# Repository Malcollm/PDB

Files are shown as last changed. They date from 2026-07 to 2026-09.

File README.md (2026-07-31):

# Humanoid Robot Power Distribution Board

This repository contains the power distribution board design for the Wiscohumanoids humanoid robot. The board distributes the main battery power to the robot’s high-current actuator system and generates regulated lower-voltage rails for compute, servos, sensors, and control electronics.

The PDB is designed around a 48 V main power system with onboard regulation for the robot’s auxiliary electronics.

## Project Overview

The power distribution board is responsible for taking the main battery input and safely distributing power throughout the robot. It includes high-current 48 V distribution, onboard buck converters, current sensing, precharge circuitry, and protection/disconnect circuitry.

The main goals of this board are:

- Distribute 48 V battery power to actuator rails
- Generate a 24 V compute rail
- Generate a 6 V servo rail for the robot hands
- Generate a 3.3 V rail for sensors and control electronics
- Monitor current on important power paths
- Limit inrush current during startup using precharge circuitry
- Separate actuator/servo power from compute/control power through protection and disconnect circuitry
- Protect the electrical system from voltage transients and fault conditions

## System Power Architecture

```text
Battery Input
    |
    |-- Precharge Circuit
    |
    |-- Main 48 V Power Rail
            |
            |-- Protection / Disconnect Circuitry
                    |
                    |-- Actuator / Servo Power Group
                    |       |
                    |       |-- 48 V Actuator Distribution
                    |       |
                    |       |-- 48 V to 6 V Buck Converter
                    |               |
                    |               |-- Hand Servos
                    |
                    |-- Compute / Control Power Group
                            |
                            |-- 48 V to 24 V Buck Converter
                            |       |
                            |       |-- Compute / Embedded Electronics
                            |
                            |-- 48 V to 3.3 V Buck Converter
                                    |
                                    |-- Sensors / Current Sensors / Control Logic
```

## Power Rails

| Rail | Purpose |
|---|---|
| 48 V | Main battery rail and actuator power distribution |
| 24 V | Compute and embedded electronics |
| 6 V | Servo motors in the robot hands |
| 3.3 V | Sensors, current sensors, and control logic |

## Major Board Features

### 48 V Actuator Distribution

The main power path distributes 48 V battery power to the robot’s actuator system. Because this rail carries the highest current on the board, the layout uses large copper pours, short current paths, and high-current connectors.

This section of the board is designed to minimize voltage drop and reduce heating under actuator load.

### Precharge Circuit

The board includes a precharge circuit to limit inrush current when the battery is connected. This is important because the board contains large bulk capacitance on the main 48 V rail.

During startup, the precharge path slowly charges the bulk capacitors before the main power path is fully enabled. This reduces stress on connectors, switches, relays, and other power components.

### Protection and Disconnect Circuitry

The PDB includes protection and disconnect circuitry that separates the main power system into two groups: the actuator/servo power group and the compute/control power group.

The actuator/servo group contains the 48 V actuator distribution and the 6 V hand servo rail. This group can be disconnected from the rest of the system so high-power motion components can be shut down independently.

The compute/control group contains the 12 V and 3.3 V rails. This allows the robot’s control electronics, sensors, and compute hardware to remain separated from the high-power actuator section.

This separation is important because it allows actuator power to be disabled while keeping control electronics available for monitoring, communication, and safe shutdown behavior.

Protection features include:

- Input transient voltage protection
- Precharge/inrush-current limiting
- Separation between actuator/servo power and compute/control power
- Reverse-current blocking where needed
- Current sensing for fault monitoring
- Support for external E-stop or main disconnect circuitry
- Bulk capacitance for load transients

### Current Sensing

Current sensors are included on important power paths so the robot can monitor how much current different parts of the system are drawing.

Current measurement is useful for:

- Detecting abnormal load conditions
- Debugging actuator behavior
- Estimating power usage
- Monitoring system health
- Adding future fault-detection logic

### Buck Converters

The PDB generates the lower-voltage rails from the main 48 V battery input using buck converters.

The onboard regulated rails are:

- 12 V for compute and embedded electronics
- 6 V for hand servos
- 3.3 V for sensors and control electronics

Each buck converter section includes the switching regulator circuit, input capacitance, output capacitance, feedback network, and supporting passives.

## Grounding

The board uses separate ground naming to keep high-current power paths and sensitive measurement/control paths organized.

Typical ground nets include:

| Net | Purpose |
|---|---|
| PGND | High-current power ground and switching converter return |
| AGND | Analog/sensor ground for feedback and current measurement circuits |

These grounds are not meant to be completely isolated systems. Instead, the separate names help control where large return currents flow and help keep sensor and feedback references cleaner.

## Design Status

This project is currently in development.

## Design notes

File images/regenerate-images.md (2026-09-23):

# Regenerating the images

Everything here is generated from the design files. A `pre-commit` hook rebuilds
it automatically and stages the results into that commit — enable it once per
clone with `git config core.hooksPath images/hooks`.

The hook only rebuilds what the commit actually affects:

| Staged change | Rebuilt |
| --- | --- |
| `Main_PDB.kicad_pcb` | `board-iso.png`, `board-top.png`, `layer-*.svg` |
| `*.kicad_sch` | `schematic.pdf` |

To rebuild by hand, run `./images/regenerate.sh` for everything, or narrow it
with `./images/regenerate.sh pcb` / `./images/regenerate.sh sch`. Set
`KICAD_CLI=...` if `kicad-cli` isn't at
`C:/Program Files/KiCad/10.0/bin/kicad-cli.exe`, or `SKIP_IMAGE_REGEN=1` before
a `git commit` to skip the hook once.

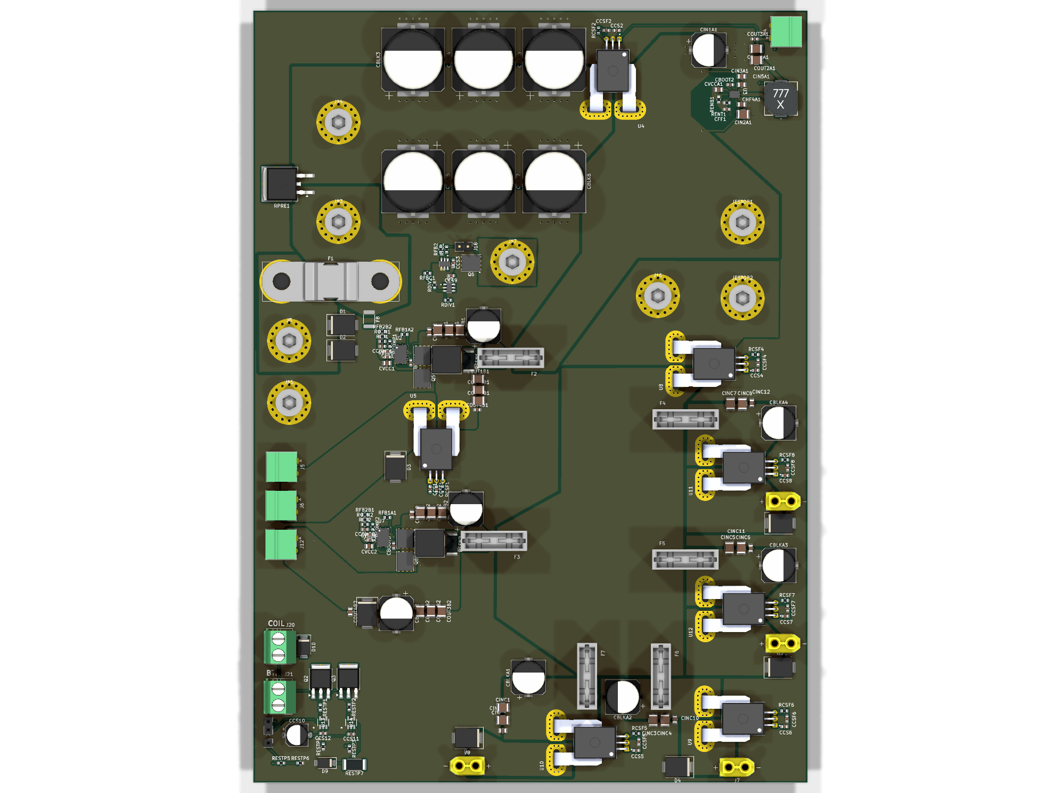
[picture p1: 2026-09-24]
images/board-top.png

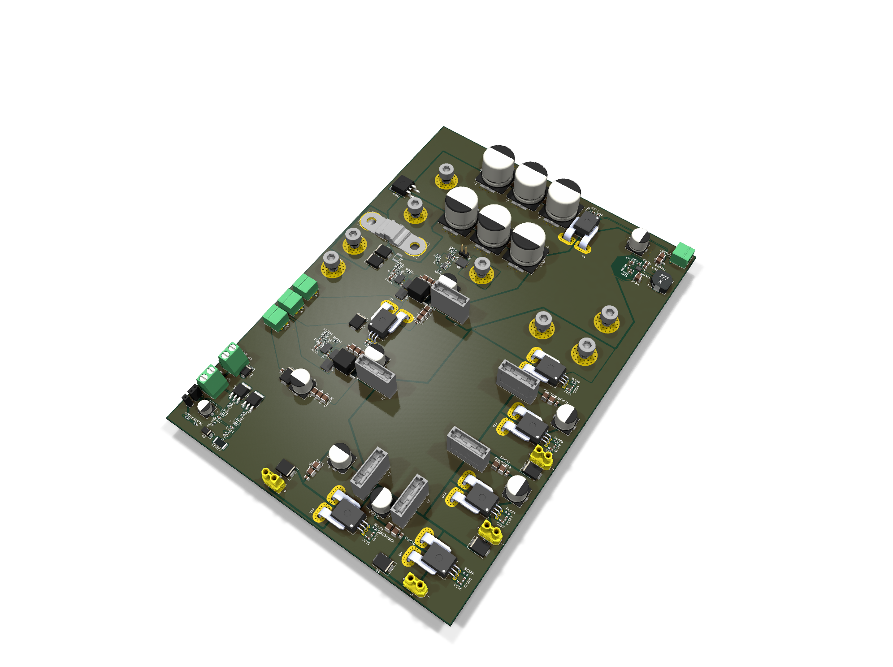
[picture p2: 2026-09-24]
images/board-iso.png

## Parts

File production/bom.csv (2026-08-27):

Designator | Footprint | Quantity | Value | LCSC Part #
CBLK3, CBLK4, CBLK5, CBLK6, CBLK7, CBLK8 | CP_Elec_18x17.5 | 6 | 470u
CBLKA1, CBLKA2, CBULK2, CIN1B2 | CP_Elec_10x10 | 4 | 100uF
CBLKA3, CBLKA4, CIN1A1, CIN1B1 | CP_Elec_10x10 | 4 | 47uF
CBOOT1, CBOOT3, CCS1, CCS2, CCS3, CCS4, CCS5, CCS6, CCS7, CCS8, CVDDA1, CVDDA2 | 0603 | 12 | 100n
CBOOT2, COUT3A1 | 0603 | 2 | 100nF
CBULK1 | CP_Elec_10x10 | 1 | 220uF
CCOMP1, CCOMP2 | 0603 | 2 | 6.8nF
CCSF1, CCSF2, CCSF4, CCSF5, CCSF6, CCSF7, CCSF8 | 0603 | 7 | 10n
CFF1 | 0603 | 1 | 20pF
CHF1, CHF2 | 0603 | 2 | 100pF
CHF4A1, CIN3A1 | 0805 | 2 | 220nF
CIN2A1 | 1210 | 1 | 4.7uF
CIN2B1, CIN2B2, CIN3B1, CIN3B2, CIN4B1, CIN4B2, CINC1, CINC2, CINC3, CINC4, CINC5, CINC6, CINC7, CINC8 | 1210 | 14 | 4.7u
CIN5A1, CIN5B1, CIN5B2, CINC10, CINC11, CINC12, CINC9, COUT4B1, COUT4B2 | 0805 | 9 | 100nF
COUT1A1, COUT2A1 | 1210 | 2 | 47uF
COUT1B1, COUT1B2, COUT2B1, COUT2B2, COUT3B1, COUT3B2 | 1210 | 6 | 22uF
CVCC1, CVCC2 | 0805 | 2 | 2.2u
CVCCA1 | 0805 | 1 | 1uF
D1, D10, D2, D3, D4, D5, D6, D7, D8 | D_SMC | 9 | TVS
F2, F3, F4, F5, F6, F7 | LITTELFUSE_178.6165.0002 | 6 | ~
J10, J7, J8, J9 | AMASS_XT30UPB-F_1x02_P5.0mm_Vertical | 4 | Conn_01x02_MountingPin
J5 | PhoenixContact_MC_1,5_2-G-3.81_1x02_P3.81mm_Horizontal | 1 | 24V Out -> Jetson
J6 | PhoenixContact_MC_1,5_2-G-3.81_1x02_P3.81mm_Horizontal | 1 | 24V Out -> USB-C-PD controller
JESTOP1 | MountingHole_5.3mm_M5_Pad | 1 | ESTOP_IN
JESTOP2 | MountingHole_5.3mm_M5_Pad | 1 | ESTOP_OUT
L1 | MSS1038183MLC | 1 | 18uH
L2 | L_Coilcraft_XAL8080-XXX | 1 | 10uH
L3 | L_Coilcraft_XAL8080-XXX | 1 | 4.7uH
Q4, Q5, Q6, Q7, Q8 | VSONP-8-1EP_5x6_P1.27mm | 5 | NMOS
RCOMP1, RCOMP2 | 0603 | 2 | 4.75k
RCON1, RCON2 | 0603 | 2 | 41.2k
RCSF1, RCSF2, RCSF4, RCSF5, RCSF6, RCSF7, RCSF8 | 0603 | 7 | 1k
RDIV1 | 0603 | 1 | 1M
RDIV2 | 0603 | 1 | 24.9k
RENB1 | 0603 | 1 | 43.2k
RENT1 | 0603 | 1 | 100k
RESTOP1, RESTOP2 | 0603 | 2 | 100
RESTOP3 | 0603 | 1 | 4.3k 1W
RESTOP4, RFB2B1, RFB2B2, RPD1, RPU1 | 0603 | 5 | 10k
RFB1, RFB2 | 0603 | 2 | 4.7R
RFB1A1 | 0603 | 1 | 64.9k
RFB1A2 | 0603 | 1 | 291k
RFBC1 | 0603 | 1 | 1.65M
RFBS1 | 0603 | 1 | 49.9k
RGND1 | 0603 | 1 | 0R
RPRE1 | 0603 | 1 | 80R
RSEN1, RSEN2 | 2512 | 2 | 0.002R
RSF1, RSF2 | 0603 | 2 | 47k
U1 | SOT95P280X145-6N | 1 | TLV3011AIDBVT
U10, U11, U12, U4, U5, U8, U9 | XDCR_ACS758LCB-100U-PFF-T | 7 | ACS758LCB-100U-PFF-T
U2 | QFN50P550X350X100-25N | 1 | LM5148RGYR
U3 | RNX0012B | 1 | LMR36015ARNXR
U6 | SOT95P280X145-6N | 1 | UCC27511DBVR

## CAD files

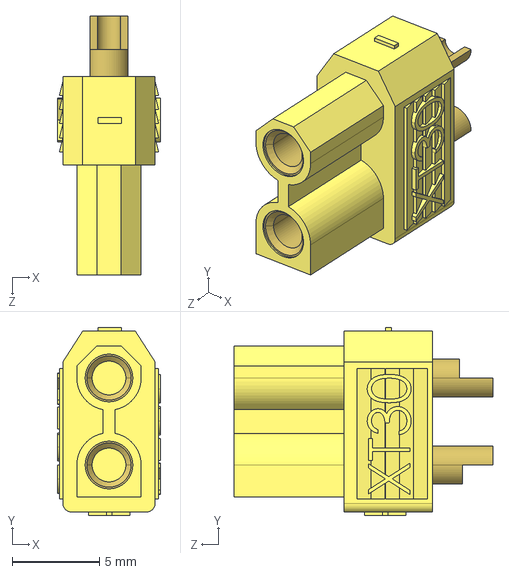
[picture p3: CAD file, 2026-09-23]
3d Models/XT30-F_m.ver.STEP
5.90 x 10.8 x 14.9 mm

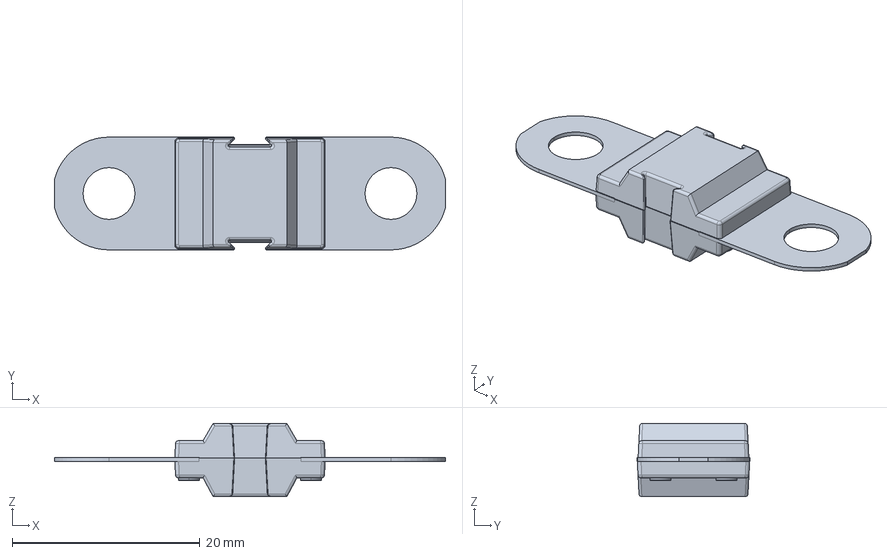
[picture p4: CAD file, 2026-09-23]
3d Models/3D_model_BF1_142.5631.0000_BF1_58v_M5_0.4mm (1).stp
41.6 x 12.0 x 7.80 mm

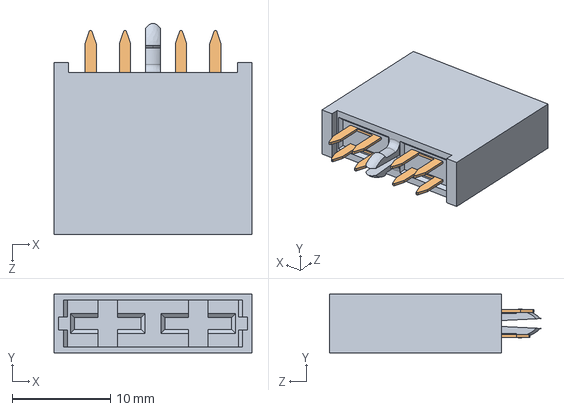
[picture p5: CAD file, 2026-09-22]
3d Models/178.6165.0000 - Holder FLR (ATO) Step model.step
20.1 x 6.00 x 21.5 mm

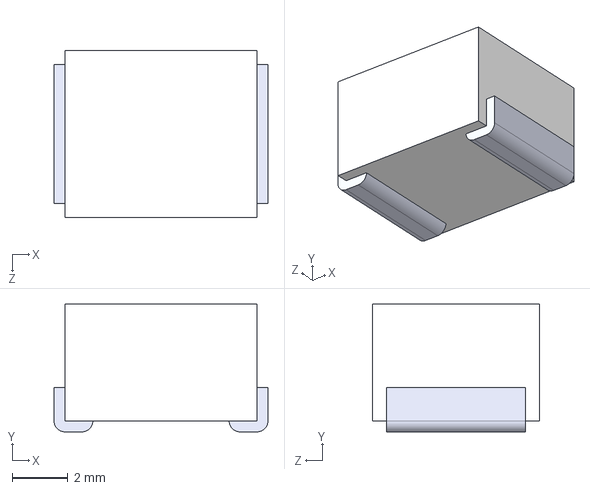
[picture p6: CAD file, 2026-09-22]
3d Models/2822HC100-RTR--3DModel-STEP-510211.STEP
7.70 x 4.60 x 6.00 mm

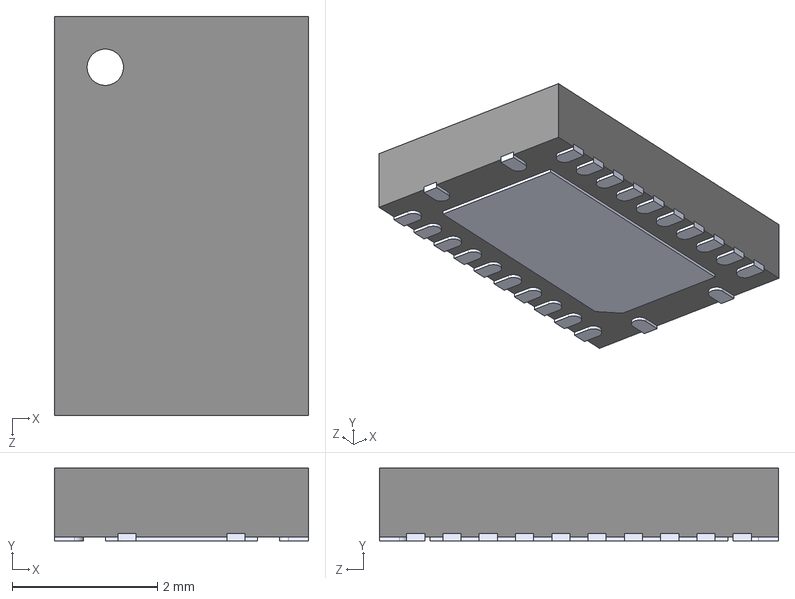
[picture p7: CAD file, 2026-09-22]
3d Models/LM5148RGYR--3DModel-STEP-56544.STEP
3.50 x 1.00 x 5.50 mm

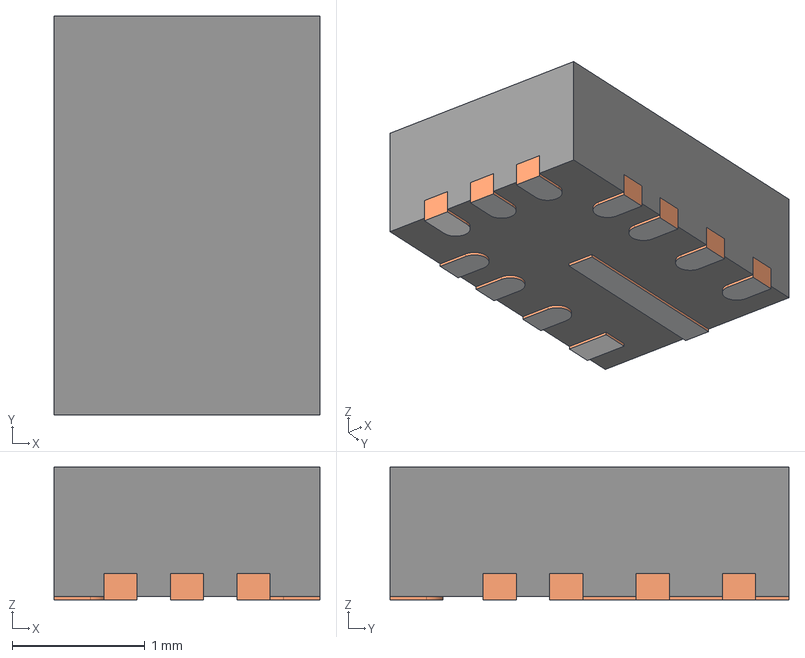
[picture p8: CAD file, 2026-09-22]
3d Models/TI_LMR3601ARNXR.stp
2.00 x 3.00 x 1.00 mm
FRAME-RNX0012A
BODY-QFN
PIN1-ID

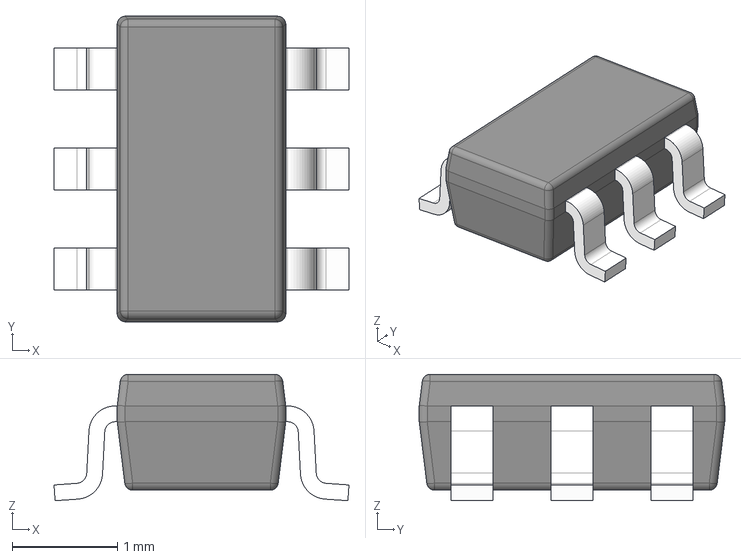
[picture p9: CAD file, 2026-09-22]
3d Models/DBV0006A.stp
2.80 x 2.90 x 1.20 mm
BODY-SOT
LEAD-SOT x 6

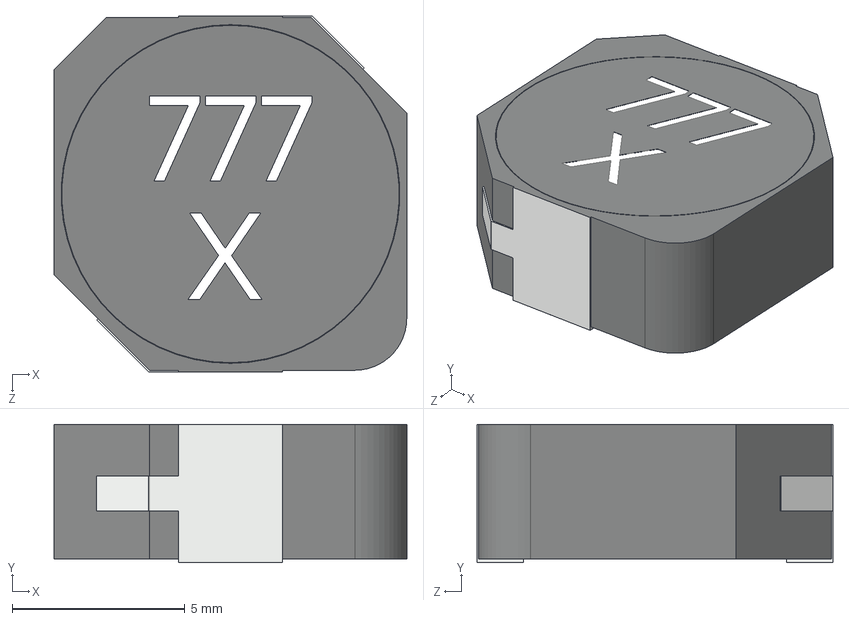
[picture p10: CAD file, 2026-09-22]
3d Models/MSS1038T.STEP
10.2 x 4.00 x 10.3 mm

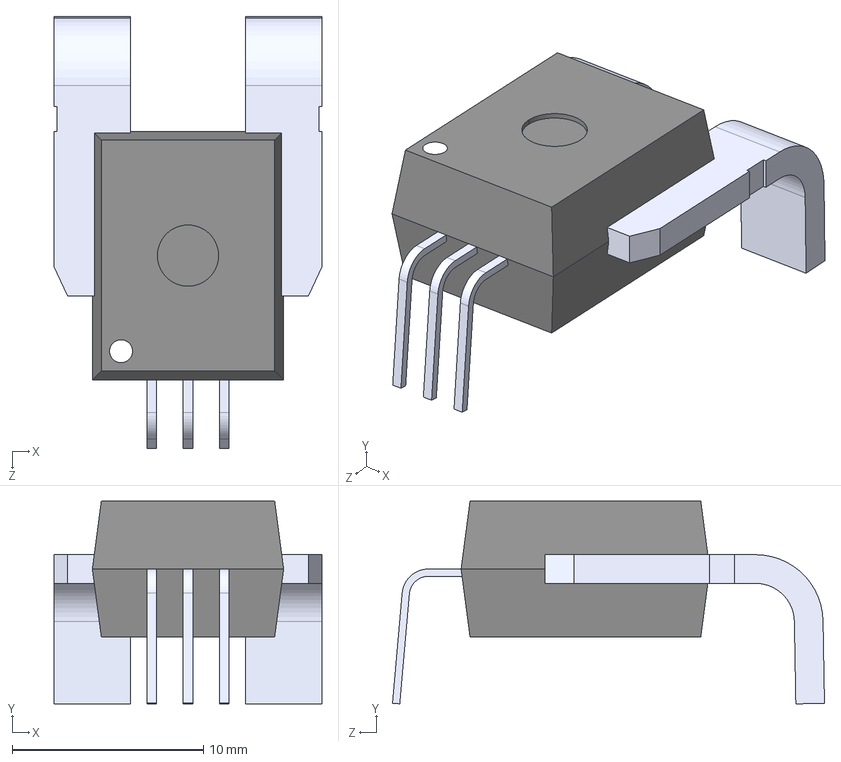
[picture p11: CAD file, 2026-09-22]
3d Models/ACS758LCB-100U-PFF-T.STEP
14.0 x 10.6 x 22.6 mm

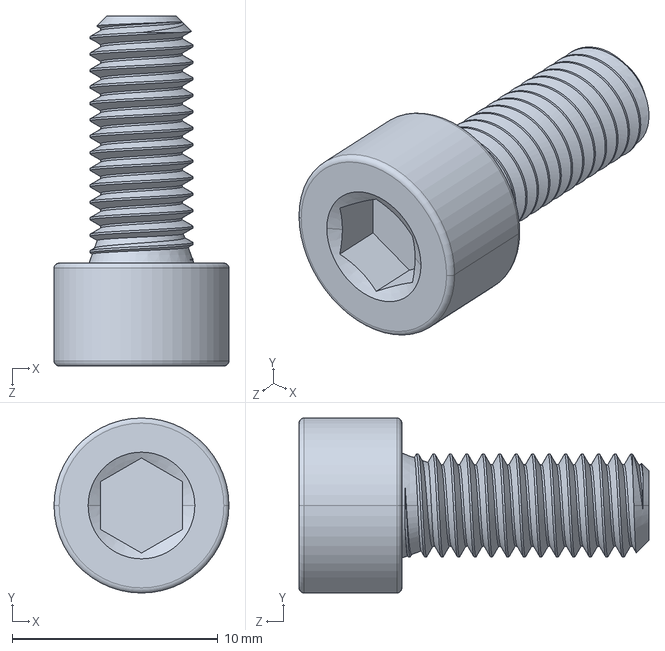
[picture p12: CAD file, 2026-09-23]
3d Models/91292A125_18-8 Stainless Steel Socket Head Screw.STEP
8.50 x 8.50 x 17.0 mm

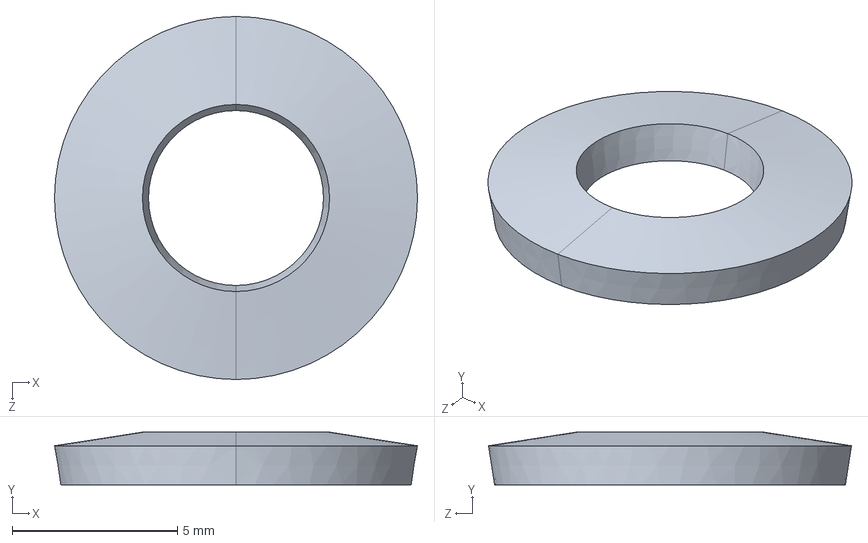
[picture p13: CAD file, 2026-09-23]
3d Models/91477A123_18-8 Stainless Steel Spring Lock Washer.STEP
11.0 x 1.60 x 11.0 mm

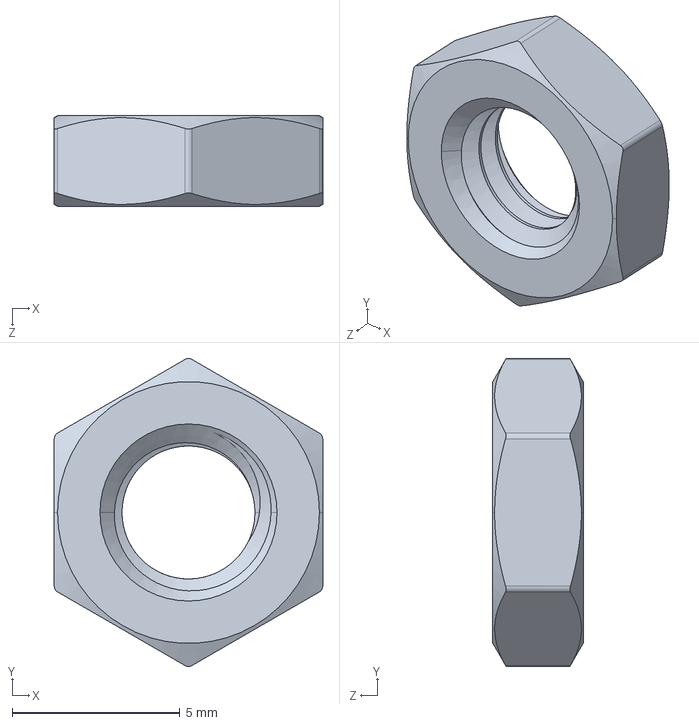
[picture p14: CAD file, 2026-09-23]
3d Models/90710A037_18-8 Stainless Steel Thin-Profile Hex Nut.STEP
8.00 x 9.18 x 2.70 mm

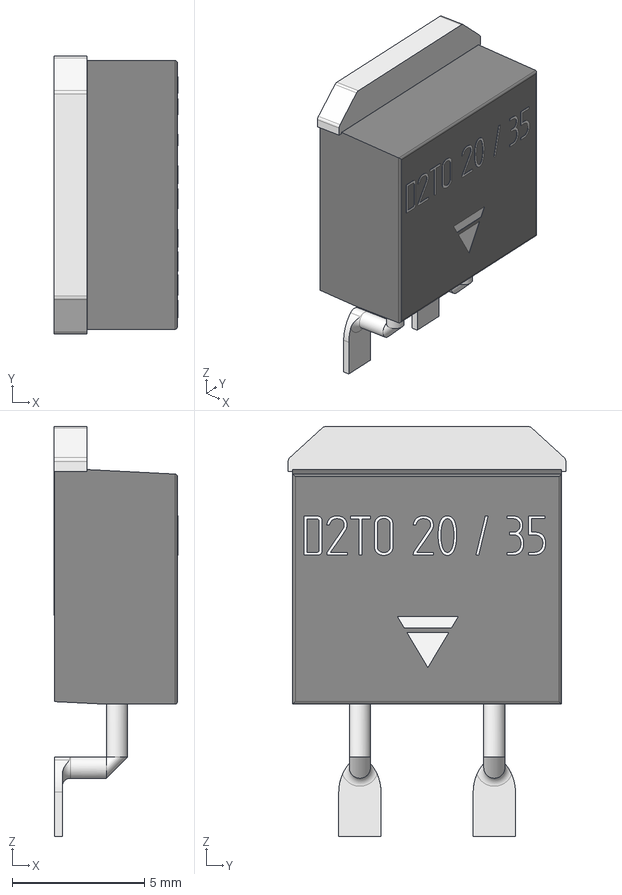
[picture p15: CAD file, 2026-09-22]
3d Models/52338943_D2TO.stp
4.69 x 10.5 x 15.5 mm
dissipateur
sortie-oa0
sortie-oa1
moulage D2TO 20_35

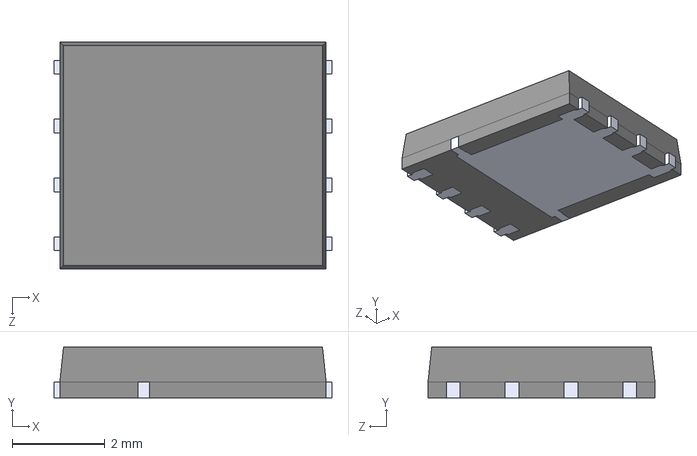
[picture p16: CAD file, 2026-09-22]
3d Models/CSD18533Q5A.STEP
6.00 x 1.10 x 4.90 mm

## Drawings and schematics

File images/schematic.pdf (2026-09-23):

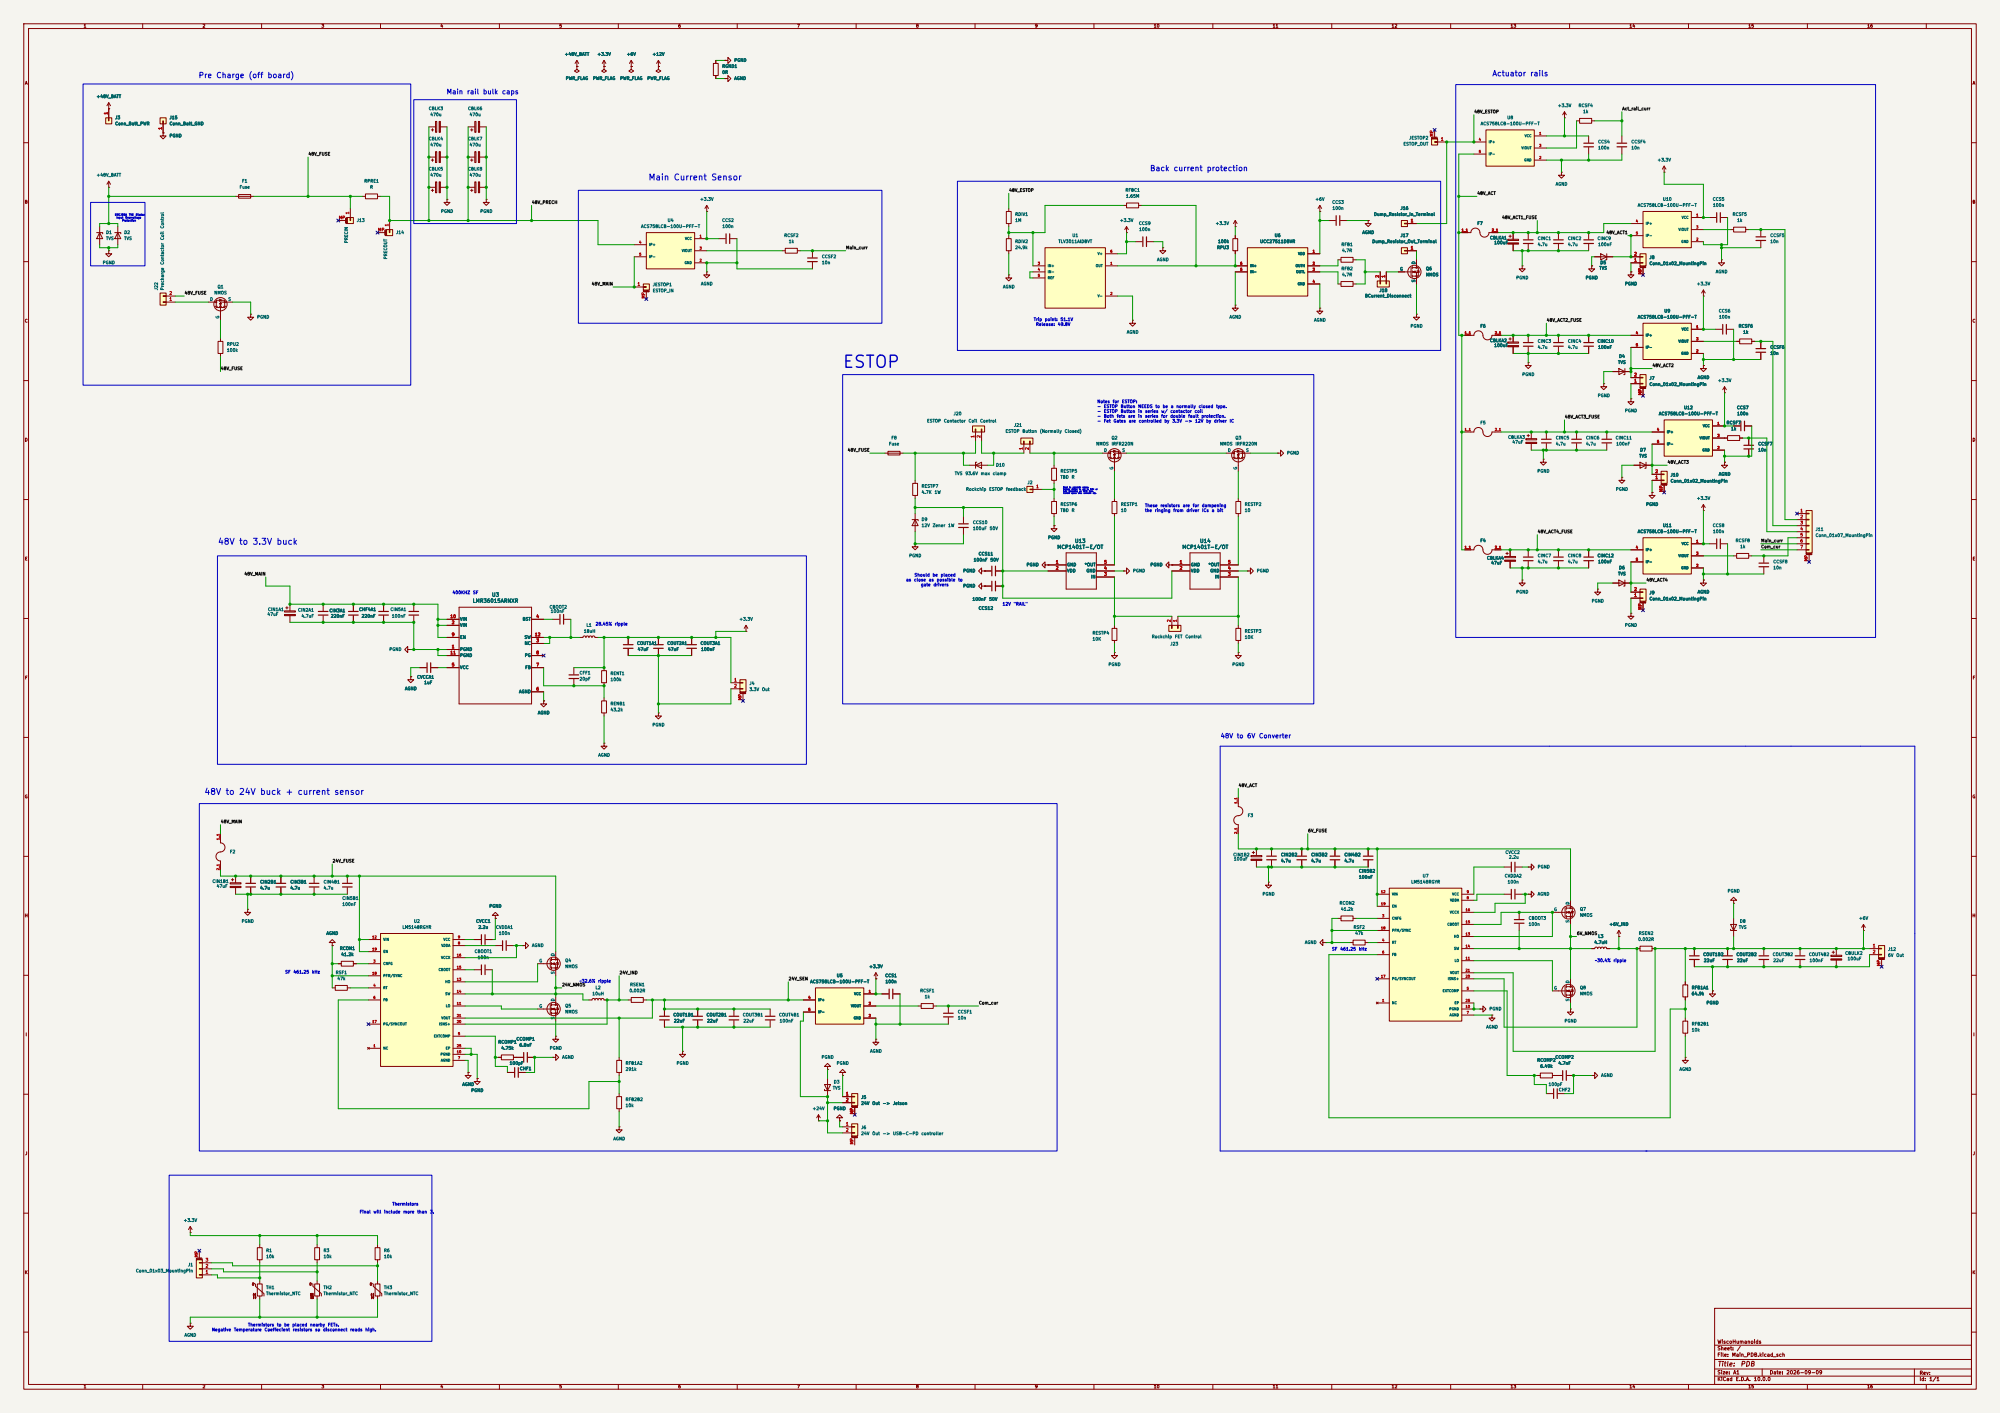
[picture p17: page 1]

Pre Charge (off board)

Trip point: 51.1V Release: 49.8V Main rail bulk caps

ESTOP
ESTOP Contactor Coil Control CCS12

Notes for ESTOP: - ESTOP Button NEEDS to be a normally closed type. - ESTOP Button in series w/ contactor coil - Both fets are in series for double fault protection. - Fet Gates are controlled by 3.3V -> 12V by driver IC

ESTOP Button (Normally Closed) GND

Need to calculate values. Voltage divider to get to 3.3v or 1.8v depending on GPIO type. Current specs also unknown atp. 12V "RAIL" 28.45% ripple

These resistors are for dampening

the ringing from driver ICs a bit 48V to 24V buck + current sensor

Should be placed
as close as possible to

24V Out -> USB-C-PD controller

Final will include more than 3.

Thermistors to be placed nearby FETs. Negative Temperature Coeffecient resistors so disconnect reads high.

Size: A1 | Rev:

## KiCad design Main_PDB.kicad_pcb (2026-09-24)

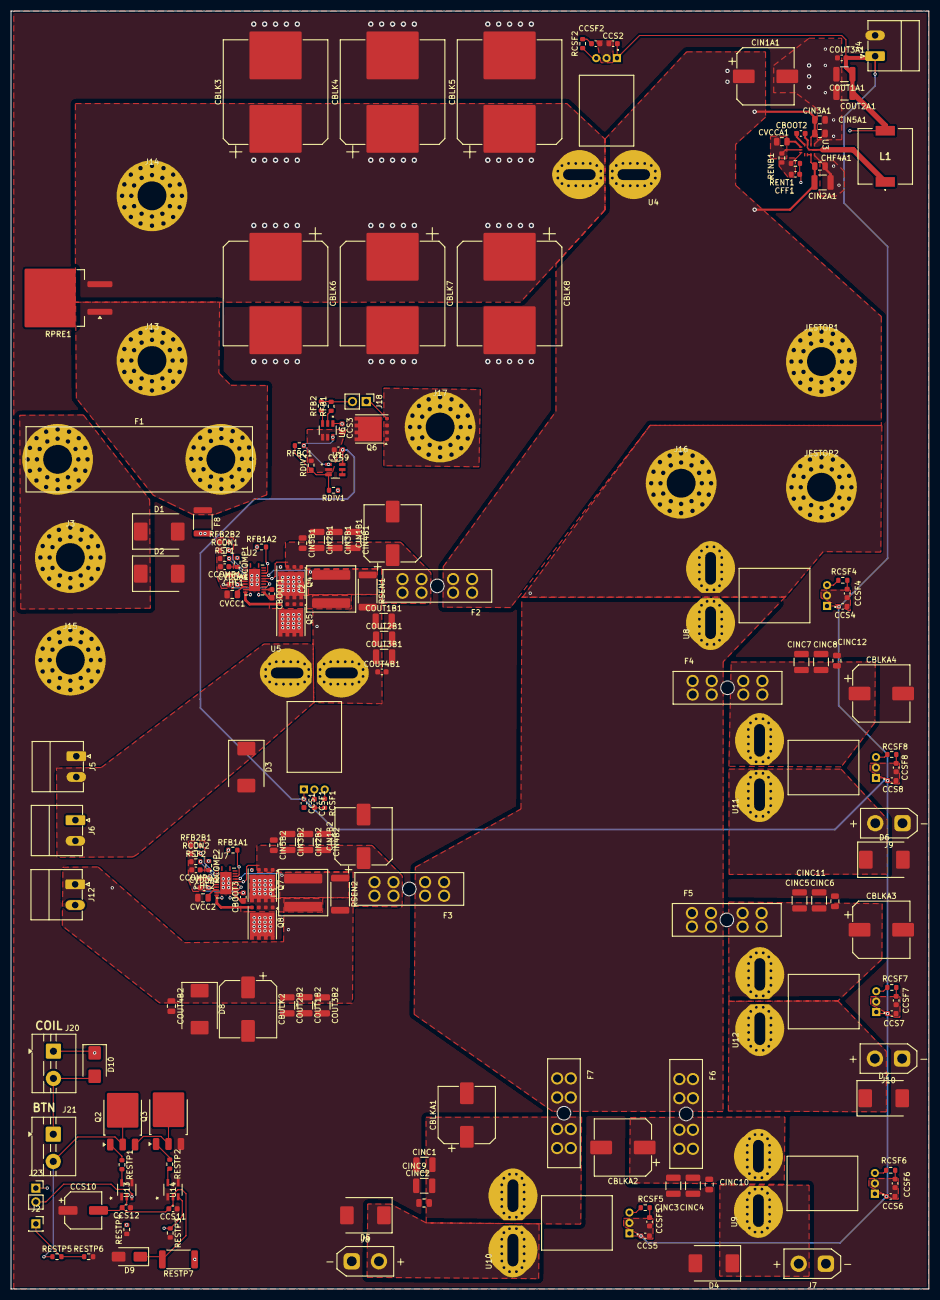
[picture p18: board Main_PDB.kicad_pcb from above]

Board: 6 copper layers, 168.6 x 234.8 mm, 178 parts (0 on the bottom side), 83 nets.

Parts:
CBLK3, CBLK4, CBLK5, CBLK6, CBLK7, CBLK8: 470u; CP_Elec_18x17.5
CBLKA1, CBLKA2: 100uF; CP_Elec_10x10
CBLKA3, CBLKA4: 47uF; CP_Elec_10x10
CBOOT1, CBOOT3: 100n; C_0603_1608Metric
CBOOT2: 100nF; C_0603_1608Metric
CBULK2: 100uF; CP_Elec_10x10
CCOMP1: 6.8nF; C_0603_1608Metric
CCOMP2: 4.7nF; C_0603_1608Metric
CCS1, CCS2, CCS3, CCS4, CCS5, CCS6, CCS7, CCS8, CCS9: 100n; C_0603_1608Metric
CCS10: 100uF 50V; CP_Elec_6.3x5.4
CCS11, CCS12: 100nF 50V; C_0603_1608Metric
CCSF1, CCSF2, CCSF4, CCSF5, CCSF6, CCSF7, CCSF8: 10n; C_0603_1608Metric
CFF1: 20pF; C_0603_1608Metric
CHF1, CHF2: 100pF; C_0603_1608Metric
CHF4A1: 220nF; C_0805_2012Metric
CIN1A1, CIN1B1: 47uF; CP_Elec_10x10
CIN1B2: 100uF; CP_Elec_10x10
CIN2A1: 4.7uF; C_1210_3225Metric
CIN2B1, CIN2B2, CIN3B1, CIN3B2, CIN4B1, CIN4B2: 4.7u; C_1210_3225Metric
CIN3A1: 220nF; C_0805_2012Metric
CIN5A1, CIN5B1, CIN5B2: 100nF; C_0805_2012Metric
CINC1, CINC2, CINC3, CINC4, CINC5, CINC6, CINC7, CINC8: 4.7u; C_1210_3225Metric
CINC9, CINC10, CINC11, CINC12: 100nF; C_0805_2012Metric
COUT1A1, COUT2A1: 47uF; C_1210_3225Metric
COUT1B1, COUT1B2, COUT2B1, COUT2B2, COUT3B1, COUT3B2: 22uF; C_1210_3225Metric
COUT3A1, COUT4B1: 100nF; C_0603_1608Metric
COUT4B2: 100nF; C_0805_2012Metric
CVCC1, CVCC2: 2.2u; C_0805_2012Metric
CVCCA1: 1uF; C_0805_2012Metric
CVDDA1, CVDDA2: 100n; C_0603_1608Metric
D1, D2, D3, D4, D5, D6, D7, D8: TVS; D_SMC
D9: 12V Zener 1W; D_SMA
D10: TVS 93.6V max clamp; D_SMB
F1: Fuse; FUSE_BF1_M5_100A
F2, F3, F4, F5, F6, F7: LITTELFUSE_178.6165.0002
F8: Fuse; Fuse_1812_4532Metric
J2: Rockchip ESTOP feedback; PinSocket_1x01_P2.54mm_Vertical
J3: Conn_Batt_PWR; MountingHole_5.3mm_M5_Pad_Via_HP
J4: 3.3V Out; PhoenixContact_MC_1,5_2-G-3.81_1x02_P3.81mm_Horizontal
J5: 24V Out -> Jetson; PhoenixContact_MC_1,5_2-G-3.81_1x02_P3.81mm_Horizontal
J6: 24V Out -> USB-C-PD controller; PhoenixContact_MC_1,5_2-G-3.81_1x02_P3.81mm_Horizontal
J7, J8, J9, J10: Conn_01x02_MountingPin; AMASS_XT30UPB-F_1x02_P5.0mm_Vertical
J12: 6V Out; PhoenixContact_MC_1,5_2-G-3.81_1x02_P3.81mm_Horizontal
J13: PRECIN; MountingHole_5.3mm_M5_Pad_Via_HP
J14: PRECOUT; MountingHole_5.3mm_M5_Pad_Via_HP
J15: Conn_Batt_GND; MountingHole_5.3mm_M5_Pad_Via_HP
J16: Dump_Resistor_In_Terminal; MountingHole_5.3mm_M5_Pad_Via_HP
J17: Dump_Resistor_Out_Terminal; MountingHole_5.3mm_M5_Pad_Via_HP
J18: BCurrent_Disconnect; PinHeader_1x02_P2.54mm_Vertical
J20: ESTOP Contactor Coil Control; TerminalBlock_MaiXu_MX126-5.0-02P_1x02_P5.00mm
J21: ESTOP Button (Normally Closed); TerminalBlock_MaiXu_MX126-5.0-02P_1x02_P5.00mm
J23: Rockchip FET Control; PinSocket_1x02_P2.54mm_Vertical
JESTOP1: ESTOP_IN; MountingHole_5.3mm_M5_Pad_Via_HP
JESTOP2: ESTOP_OUT; MountingHole_5.3mm_M5_Pad_Via_HP
L1: 18uH; MSS1038183MLC
L2: 10uH; L_Coilcraft_XAL8080-XXX
L3: 4.7uH; L_Coilcraft_XAL8080-XXX
Q2, Q3: NMOS IRFR220N; TO-252-3_TabPin2
Q4, Q5, Q6, Q7, Q8: NMOS; VSONP-8-1EP_5x6_P1.27mm
RCOMP1: 4.75k; R_0603_1608Metric
RCOMP2: 6.49k; R_0603_1608Metric
RCON1, RCON2: 41.2k; R_0603_1608Metric
RCSF1, RCSF2, RCSF4, RCSF5, RCSF6, RCSF7, RCSF8: 1k; R_0603_1608Metric
RDIV1: 1M; R_0603_1608Metric
RDIV2: 24.9k; R_0603_1608Metric
RENB1: 43.2k; R_0603_1608Metric
RENT1: 100k; R_0603_1608Metric
RESTP1, RESTP2: 10; R_0603_1608Metric
RESTP3, RESTP4: 10K; R_0603_1608Metric
RESTP5, RESTP6: TBD R; R_0603_1608Metric
RESTP7: 4.7K 1W; R_2512_6332Metric
RFB1, RFB2: 4.7R; R_0603_1608Metric
RFB1A1: 64.9k; R_0603_1608Metric
RFB1A2: 291k; R_0603_1608Metric
RFB2B1, RFB2B2: 10k; R_0603_1608Metric
RFBC1: 1.65M; R_0603_1608Metric
RPRE1: R; TO-263-2_Resistor
RSEN1, RSEN2: 0.002R; R_2512_6332Metric
RSF1, RSF2: 47k; R_0603_1608Metric
U1: TLV3011AIDBVT; SOT95P280X145-6N
U2, U7: LM5148RGYR; QFN50P550X350X100-25N
U3: LMR36015ARNXR; RNX0012B
U4, U5, U8, U9, U10, U11, U12: ACS758LCB-100U-PFF-T; XDCR_ACS758LCB-100U-PFF-T
U6: UCC27511DBVR; SOT95P280X145-6N
U13, U14: MCP1401T-E/OT; SOT-23-5_MC_MCH

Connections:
+3.3V: CCS1.1, CCS2.2, CCS4.2, CCS5.1, CCS6.1, CCS7.1, CCS8.1, CCS9.1, CFF1.1, COUT1A1.1, COUT2A1.1, COUT3A1.1, J4.1, L1.2, RENT1.1, U1.6 (V+), U4.1 (VCC), U5.1 (VCC), U8.1 (VCC), U9.1 (VCC), U10.1 (VCC), U11.1 (VCC), U12.1 (VCC)
+6V: CBULK2.1, CCS3.1, COUT1B2.1, COUT2B2.1, COUT3B2.1, COUT4B2.1, D8.1 (K), J12.1, RFB1A1.2, RSEN2.2, U6.1 (VDD), U7.21 (VOUT)
+6V_IND: L3.2, RSEN2.1, U7.20 (ISNS+)
+24V: D3.1 (K), J5.2, J6.2, U5.5 (IP-), U5.5_1 (IP-), U5.5_2 (IP-), U5.5_3 (IP-), U5.5_4 (IP-), U5.5_5 (IP-), U5.5_6 (IP-), U5.5_7 (IP-), U5.5_8 (IP-), U5.5_9 (IP-), U5.5_10 (IP-), U5.5_11 (IP-), U5.5_12 (IP-), U5.5_13 (IP-), U5.5_14 (IP-), U5.5_15 (IP-), U5.5_16 (IP-)
+48V_BATT: D1.1 (K), D2.1 (K), F1.1, J3.1 (Pin_1_1)
/6V_FUSE: CIN1B2.1, CIN2B2.2, CIN3B2.2, CIN4B2.2, CIN5B2.2, F3.2_1, F3.2_2, F3.2_3, F3.2_4, Q7.1 (D), U7.12 (VIN), U7.19 (EN)
/6V_NMOS: CBOOT3.1, L3.1, Q7.3 (S), Q8.1 (D), U7.14 (SW)
/24V_FUSE: CIN1B1.1, CIN2B1.2, CIN3B1.2, CIN4B1.2, CIN5B1.2, F2.2_1, F2.2_2, F2.2_3, F2.2_4, Q4.1 (D), U2.12 (VIN), U2.19 (EN)
/24V_IND: L2.2, RSEN1.1, U2.20 (ISNS+)
/24V_NMOS: CBOOT1.2, L2.1, Q4.3 (S), Q5.1 (D), U2.14 (SW)
/24V_SEN: COUT1B1.1, COUT2B1.1, COUT3B1.1, COUT4B1.1, RFB1A2.2, RSEN1.2, U2.21 (VOUT), U5.4 (IP+), U5.4_1 (IP+), U5.4_2 (IP+), U5.4_3 (IP+), U5.4_4 (IP+), U5.4_5 (IP+), U5.4_6 (IP+), U5.4_7 (IP+), U5.4_8 (IP+), U5.4_9 (IP+), U5.4_10 (IP+), U5.4_11 (IP+), U5.4_12 (IP+), U5.4_13 (IP+), U5.4_14 (IP+), U5.4_15 (IP+), U5.4_16 (IP+)
/48V_ACT: F3.1_1, F3.1_2, F3.1_3, F3.1_4, F4.1_1, F4.1_2, F4.1_3, F4.1_4, F5.1_1, F5.1_2, F5.1_3, F5.1_4, F6.1_1, F6.1_2, F6.1_3, F6.1_4, F7.1_1, F7.1_2, F7.1_3, F7.1_4, U8.5 (IP-), U8.5_1 (IP-), U8.5_2 (IP-), U8.5_3 (IP-), U8.5_4 (IP-), U8.5_5 (IP-), U8.5_6 (IP-), U8.5_7 (IP-), U8.5_8 (IP-), U8.5_9 (IP-), U8.5_10 (IP-), U8.5_11 (IP-), U8.5_12 (IP-), U8.5_13 (IP-), U8.5_14 (IP-), U8.5_15 (IP-), U8.5_16 (IP-)
/48V_ACT1: D5.1 (K), J8.2, U10.5 (IP-), U10.5_1 (IP-), U10.5_2 (IP-), U10.5_3 (IP-), U10.5_4 (IP-), U10.5_5 (IP-), U10.5_6 (IP-), U10.5_7 (IP-), U10.5_8 (IP-), U10.5_9 (IP-), U10.5_10 (IP-), U10.5_11 (IP-), U10.5_12 (IP-), U10.5_13 (IP-), U10.5_14 (IP-), U10.5_15 (IP-), U10.5_16 (IP-)
/48V_ACT1_FUSE: CBLKA1.1, CINC1.2, CINC2.2, CINC9.1, F7.2_1, F7.2_2, F7.2_3, F7.2_4, U10.4 (IP+), U10.4_1 (IP+), U10.4_2 (IP+), U10.4_3 (IP+), U10.4_4 (IP+), U10.4_5 (IP+), U10.4_6 (IP+), U10.4_7 (IP+), U10.4_8 (IP+), U10.4_9 (IP+), U10.4_10 (IP+), U10.4_11 (IP+), U10.4_12 (IP+), U10.4_13 (IP+), U10.4_14 (IP+), U10.4_15 (IP+), U10.4_16 (IP+)
/48V_ACT2: D4.1 (K), J7.2, U9.5 (IP-), U9.5_1 (IP-), U9.5_2 (IP-), U9.5_3 (IP-), U9.5_4 (IP-), U9.5_5 (IP-), U9.5_6 (IP-), U9.5_7 (IP-), U9.5_8 (IP-), U9.5_9 (IP-), U9.5_10 (IP-), U9.5_11 (IP-), U9.5_12 (IP-), U9.5_13 (IP-), U9.5_14 (IP-), U9.5_15 (IP-), U9.5_16 (IP-)
/48V_ACT2_FUSE: CBLKA2.1, CINC3.2, CINC4.2, CINC10.1, F6.2_1, F6.2_2, F6.2_3, F6.2_4, U9.4 (IP+), U9.4_1 (IP+), U9.4_2 (IP+), U9.4_3 (IP+), U9.4_4 (IP+), U9.4_5 (IP+), U9.4_6 (IP+), U9.4_7 (IP+), U9.4_8 (IP+), U9.4_9 (IP+), U9.4_10 (IP+), U9.4_11 (IP+), U9.4_12 (IP+), U9.4_13 (IP+), U9.4_14 (IP+), U9.4_15 (IP+), U9.4_16 (IP+)
/48V_ACT3: D7.1 (K), J10.2, U12.5 (IP-), U12.5_1 (IP-), U12.5_2 (IP-), U12.5_3 (IP-), U12.5_4 (IP-), U12.5_5 (IP-), U12.5_6 (IP-), U12.5_7 (IP-), U12.5_8 (IP-), U12.5_9 (IP-), U12.5_10 (IP-), U12.5_11 (IP-), U12.5_12 (IP-), U12.5_13 (IP-), U12.5_14 (IP-), U12.5_15 (IP-), U12.5_16 (IP-)
/48V_ACT3_FUSE: CBLKA3.1, CINC5.2, CINC6.2, CINC11.1, F5.2_1, F5.2_2, F5.2_3, F5.2_4, U12.4 (IP+), U12.4_1 (IP+), U12.4_2 (IP+), U12.4_3 (IP+), U12.4_4 (IP+), U12.4_5 (IP+), U12.4_6 (IP+), U12.4_7 (IP+), U12.4_8 (IP+), U12.4_9 (IP+), U12.4_10 (IP+), U12.4_11 (IP+), U12.4_12 (IP+), U12.4_13 (IP+), U12.4_14 (IP+), U12.4_15 (IP+), U12.4_16 (IP+)
/48V_ACT4: D6.1 (K), J9.2, U11.5 (IP-), U11.5_1 (IP-), U11.5_2 (IP-), U11.5_3 (IP-), U11.5_4 (IP-), U11.5_5 (IP-), U11.5_6 (IP-), U11.5_7 (IP-), U11.5_8 (IP-), U11.5_9 (IP-), U11.5_10 (IP-), U11.5_11 (IP-), U11.5_12 (IP-), U11.5_13 (IP-), U11.5_14 (IP-), U11.5_15 (IP-), U11.5_16 (IP-)
/48V_ACT4_FUSE: CBLKA4.1, CINC7.2, CINC8.2, CINC12.1, F4.2_1, F4.2_2, F4.2_3, F4.2_4, U11.4 (IP+), U11.4_1 (IP+), U11.4_2 (IP+), U11.4_3 (IP+), U11.4_4 (IP+), U11.4_5 (IP+), U11.4_6 (IP+), U11.4_7 (IP+), U11.4_8 (IP+), U11.4_9 (IP+), U11.4_10 (IP+), U11.4_11 (IP+), U11.4_12 (IP+), U11.4_13 (IP+), U11.4_14 (IP+), U11.4_15 (IP+), U11.4_16 (IP+)
/48V_ESTOP: J16.1 (Pin_1_1), JESTOP2.1 (Pin_1_1), RDIV1.1, U8.4 (IP+), U8.4_1 (IP+), U8.4_2 (IP+), U8.4_3 (IP+), U8.4_4 (IP+), U8.4_5 (IP+), U8.4_6 (IP+), U8.4_7 (IP+), U8.4_8 (IP+), U8.4_9 (IP+), U8.4_10 (IP+), U8.4_11 (IP+), U8.4_12 (IP+), U8.4_13 (IP+), U8.4_14 (IP+), U8.4_15 (IP+), U8.4_16 (IP+)
/48V_FUSE: F1.2, F8.1, J13.1 (Pin_1_1), RPRE1.1
/48V_MAIN: CHF4A1.1, CIN1A1.1, CIN2A1.1, CIN3A1.1, CIN5A1.1, F2.1_1, F2.1_2, F2.1_3, F2.1_4, JESTOP1.1 (Pin_1_1), U3.2 (VIN), U3.9 (EN), U3.10 (VIN), U4.5 (IP-), U4.5_1 (IP-), U4.5_2 (IP-), U4.5_3 (IP-), U4.5_4 (IP-), U4.5_5 (IP-), U4.5_6 (IP-), U4.5_7 (IP-), U4.5_8 (IP-), U4.5_9 (IP-), U4.5_10 (IP-), U4.5_11 (IP-), U4.5_12 (IP-), U4.5_13 (IP-), U4.5_14 (IP-), U4.5_15 (IP-), U4.5_16 (IP-)
/48V_PRECH: CBLK3.1, CBLK4.1, CBLK5.1, CBLK6.1, CBLK7.1, CBLK8.1, J14.1 (Pin_1_1), RPRE1.2, U4.4 (IP+), U4.4_1 (IP+), U4.4_2 (IP+), U4.4_3 (IP+), U4.4_4 (IP+), U4.4_5 (IP+), U4.4_6 (IP+), U4.4_7 (IP+), U4.4_8 (IP+), U4.4_9 (IP+), U4.4_10 (IP+), U4.4_11 (IP+), U4.4_12 (IP+), U4.4_13 (IP+), U4.4_14 (IP+), U4.4_15 (IP+), U4.4_16 (IP+)
/Act_rail_curr: CCSF4.2, RCSF4.2
/Com_cur: CCSF1.2, RCSF1.2
/Main_curr: CCSF2.2, RCSF2.2
AGND: CCOMP1.2, CCOMP2.2, CCS1.2, CCS2.1, CCS3.2, CCS4.1, CCS5.2, CCS6.2, CCS7.2, CCS8.2, CCS9.2, CCSF1.1, CCSF2.1, CCSF4.1, CCSF5.1, CCSF6.1, CCSF7.1, CCSF8.1, CHF1.2, CHF2.2, CVCCA1.1, CVDDA1.1, CVDDA2.1, RCON1.1, RCON2.1, RDIV2.2, RENB1.2, RFB2B1.1, RFB2B2.1, RSF1.1, RSF2.1, U1.2 (V-), U2.7 (AGND), U2.16 (VCCX), U2.18 (PFM/SYNC), U3.6 (AGND), U4.2 (GND), U5.2 (GND), U6.4 (GND), U6.5 (IN-), U7.7 (AGND), U7.16 (VCCX), U7.18 (PFM/SYNC), U8.2 (GND), U9.2 (GND), U10.2 (GND), U11.2 (GND), U12.2 (GND)
unnamed: CCOMP1.1, RCOMP1.2
unnamed: CCOMP2.1, RCOMP2.2
unnamed: CCS10.2, CCS11.2, CCS12.2, D9.1 (K), RESTP7.2, U13.2 (VDD), U14.2 (VDD)
unnamed: D10.2 (A), J20.2, J21.1
unnamed: D10.1 (K), F8.2, J20.1, RESTP7.1
unnamed: J2.1 (Pin_1_1), RESTP5.2, RESTP6.1
unnamed: CCSF5.2, RCSF5.2
unnamed: CCSF6.2, RCSF6.2
unnamed: CCSF7.2, RCSF7.2
unnamed: CCSF8.2, RCSF8.2
unnamed: J17.1 (Pin_1_1), Q6.1 (D)
unnamed: J18.1, Q6.2 (G)
unnamed: J18.2, RFB1.2, RFB2.2
unnamed: J21.2, Q2.2 (D), RESTP5.1
unnamed: J23.1, RESTP3.1, U14.3 (IN)
unnamed: J23.2, RESTP4.2, U13.3 (IN)
unnamed: Q2.1 (G), RESTP1.1
unnamed: Q2.3 (S), Q3.2 (D)
unnamed: Q3.1 (G), RESTP2.1
unnamed: Q4.2 (G), U2.13 (HO)
unnamed: Q5.2 (G), U2.11 (LO)
unnamed: CBOOT3.2, Q7.2 (G), U7.13 (HO), U7.15 (CBOOT)
unnamed: Q8.2 (G), U7.11 (LO)
unnamed: RDIV1.2, RDIV2.1, RFBC1.2, U1.3 (IN+)
unnamed: U1.4 (IN-), U1.5 (REF)
unnamed: RFBC1.1, U1.1 (OUT), U6.6 (IN+)
unnamed: CBOOT1.1, U2.15 (CBOOT)
unnamed: RCON1.2, U2.3 (CNFG)
unnamed: CHF1.1, RCOMP1.1, U2.5 (EXTCOMP)
unnamed: RFB1A2.1, RFB2B2.2, U2.6 (FB)
unnamed: RSF1.2, U2.4 (RT)
unnamed: CVCC1.1, U2.9 (VCC)
unnamed: CVDDA1.2, U2.8 (VDDA)
unnamed: CBOOT2.1, U3.4 (BST)
unnamed: CFF1.2, RENB1.1, RENT1.2, U3.7 (FB)
unnamed: CBOOT2.2, L1.1, U3.3 (NC), U3.12 (SW)
unnamed: CVCCA1.2, U3.5 (VCC)
unnamed: RCSF2.1, U4.3 (VIOUT)
unnamed: RCSF1.1, U5.3 (VIOUT)
unnamed: RFB1.1, U6.2 (OUTH)
unnamed: RFB2.1, U6.3 (OUTL)
unnamed: RCON2.2, U7.3 (CNFG)
unnamed: CHF2.1, RCOMP2.1, U7.5 (EXTCOMP)
unnamed: RFB1A1.1, RFB2B1.2, U7.6 (FB)
unnamed: RSF2.2, U7.4 (RT)
unnamed: CVCC2.1, U7.9 (VCC)
unnamed: CVDDA2.2, U7.8 (VDDA)
unnamed: RCSF4.1, U8.3 (VIOUT)
unnamed: RCSF6.1, U9.3 (VIOUT)
unnamed: RCSF5.1, U10.3 (VIOUT)
unnamed: RCSF8.1, U11.3 (VIOUT)
unnamed: RCSF7.1, U12.3 (VIOUT)
unnamed: RESTP1.2, U13.5 (*OUT)
unnamed: RESTP2.2, U14.5 (*OUT)
PGND: CBLK3.2, CBLK4.2, CBLK5.2, CBLK6.2, CBLK7.2, CBLK8.2, CBLKA1.2, CBLKA2.2, CBLKA3.2, CBLKA4.2, CBULK2.2, CCS10.1, CCS11.1, CCS12.1, CHF4A1.2, CIN1A1.2, CIN1B1.2, CIN1B2.2, CIN2A1.2, CIN2B1.1, CIN2B2.1, CIN3A1.2, CIN3B1.1, CIN3B2.1, CIN4B1.1, CIN4B2.1, CIN5A1.2, CIN5B1.1, CIN5B2.1, CINC1.1, CINC2.1, CINC3.1, CINC4.1, CINC5.1, CINC6.1, CINC7.1, CINC8.1, CINC9.2, CINC10.2, CINC11.2, CINC12.2, COUT1A1.2, COUT1B1.2, COUT1B2.2, COUT2A1.2, COUT2B1.2, COUT2B2.2, COUT3A1.2, COUT3B1.2, COUT3B2.2, COUT4B1.2, COUT4B2.2, CVCC1.2, CVCC2.2, D1.2 (A), D2.2 (A), D3.2 (A), D4.2 (A), D5.2 (A), D6.2 (A), D7.2 (A), D8.2 (A), D9.2 (A), J4.2, J5.1, J6.1, J7.1, J8.1, J9.1, J10.1, J12.2, J15.1 (Pin_1_1), Q3.3 (S), Q5.3 (S), Q6.3 (S), Q8.3 (S), RESTP3.2, RESTP4.1, RESTP6.2, U2.10 (PGND), U2.25 (EP), U3.1 (PGND), U3.11 (PGND), U7.10 (PGND), U7.25 (EP), U13.1 (GND), U13.4 (GND), U14.1 (GND), U14.4 (GND)

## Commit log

2026-04-06 Added input cap at 48->24 comp buck
    [Main_PDB.kicad_sch]
2026-04-10 Converted 24V actuator rails to 48V actuator rails
    [Main_PDB.kicad_sch]
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2026-04-11 Added Pre charge tag
    [Main_PDB.kicad_sch]
2026-04-12 File added for master
    [LM5143_Buck.kicad_sch]
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2026-04-18 Added updated 48 to 3.3v converter
    [Main_PDB.kicad_sch]
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2026-04-19 Added regen MOSFET drivers
    [Main_PDB.kicad_sch]
2026-04-19 Added PMOS to precharge
    [Main_PDB.kicad_sch]
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2026-04-21 Started on high side fet driver for precharge
    [Main_PDB.kicad_sch]
2026-04-21 48V -> 6V buck added
    [Main_PDB.kicad_sch]
2026-04-21 Fixed 48V -> 6V buck power source
    [Main_PDB.kicad_sch]
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2026-04-23 48->6 power conection update
    [Main_PDB.kicad_sch]
2026-04-24 Added precharge high side nmos controler
    [Main_PDB.kicad_sch]
2026-04-24 Changed current sensors to 3.3V
    [Main_PDB.kicad_sch]
2026-04-26 tvs diodes for overvoltage protection at the battery input
    [Main_PDB.kicad_sch]
2026-04-26 added TVS diodes for overvoltage protection for each actuator rail output and also the 24v and 6v rail outputs
    [Main_PDB.kicad_sch]
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2026-04-27 Changed 48->24 to 48->12
    [Main_PDB.kicad_sch]
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2026-04-29 updated component values for 6v convert
    [Main_PDB.kicad_sch]
2026-04-29 updated grounds for converters, need to double check grounds for current sense. Did not adjust grounds on actuators/precharge. Added pull up resistor on 6v PG output.
    [Main_PDB.kicad_sch]
2026-04-29 changed ground for ext comp circuit
    [Main_PDB.kicad_sch]
2026-04-29 added thermistors in lower left hand side, exact values, quantity,and need for more specific measurement will be determined during testing/tracing.
    [Main_PDB.kicad_sch]
2026-04-29 Grounding and inductor and output caps on 12V buck
    [Main_PDB.kicad_sch]
2026-04-29 Added compute buck cap
    [Main_PDB.kicad_sch]
2026-04-29 Added input caps to 6V buck
    [Main_PDB.kicad_sch]
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2026-05-31 TVS diode grounding changes
    [Main_PDB.kicad_sch]
2026-06-01 input/output caps on 3.3V rail update
    [Main_PDB.kicad_sch]
2026-06-01 Revisions for 3.3V buck + Added footprints
    [Main_PDB.kicad_sch]
2026-06-02 Started updating 48->12 buck footprints (caps and res)
    [Main_PDB.kicad_pcb, Main_PDB.kicad_sch]
2026-06-02 Added input cap to 48->12 buck
    [Main_PDB.kicad_sch]
2026-06-02 Changed sf and ripple current %
    [Main_PDB.kicad_sch]
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2026-06-05 Setup main pour topology
    [Main_PDB.kicad_pcb]
2026-06-07 added footprints onto the PCB
    [Main_PDB.kicad_pcb]
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2026-06-14 Fixing Kicad crash
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2026-06-15 Changed prechage to relay based system and added footprints to PCB
    [Main_PDB.kicad_pcb]
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2026-06-24 Added nets to all high current connections
    [Main_PDB.kicad_pcb]
2026-06-24 PCB for bulk caps and main curr sen
    [Main_PDB.kicad_pcb]
2026-06-25 PCB buck caps and 3.3V buck
    [Main_PDB.kicad_pcb]
2026-06-25 Adj vias in 3.3V buck
    [Main_PDB.kicad_pcb]
2026-06-25 redid 3.3 buck layout on pcb
    [Main_PDB.kicad_pcb]
2026-06-25 edited pgnd (upper) on 3.3V buck
    [Main_PDB.kicad_pcb]
2026-06-25 added additonal vias in pgnd pour
    [Main_PDB.kicad_pcb]
2026-06-26 bulk caps relayout and added power pours on bottom layer
    [Main_PDB.kicad_pcb]
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2026-06-27 fixed grounding error
    [Main_PDB.kicad_pcb]
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2026-06-30 adj decoupling caps placements
    [Main_PDB.kicad_pcb]
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2026-07-06 sorted components for 12V buck
    [Main_PDB.kicad_pcb]
2026-07-09 begun placement for 12V buck
    [Main_PDB.kicad_pcb]
2026-07-17 12V buck layout progressed
    [Main_PDB.kicad_pcb]
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2026-07-31 Changed 12V buck to 24V buck
    [Main_PDB.kicad_sch]
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2026-07-31 Added connectors for 24V output
    [Main_PDB.kicad_sch]
2026-08-16 Added comparitor to regen protection
    [Main_PDB.kicad_sch]
2026-08-16 Added footprint for comparitor
    [Main_PDB.kicad_sch]
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2026-08-16 started on redoing precharge
    [Main_PDB.kicad_sch]
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2026-08-16 Added M5 mounting for power pins on ESTOP
    [Main_PDB.kicad_sch]
2026-08-16 ESTOP curr sen PCB layout
    [Main_PDB.kicad_pcb]
2026-08-17 Added actuator connector footprints
    [Main_PDB.kicad_pcb, Main_PDB.kicad_sch]
2026-08-17 12V buck almost finished
    [Main_PDB.kicad_pcb]
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2026-08-18 small buck fixes
    [Main_PDB.kicad_pcb]
2026-08-18 more small buck changes
    [Main_PDB.kicad_pcb]
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2026-08-23 Current S PCB place
    [Main_PDB.kicad_pcb]
2026-08-24 act rails on PCB started
    [Main_PDB.kicad_pcb, Main_PDB.kicad_sch]
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2026-08-31 fixed merge
    [Main_PDB.kicad_pcb]
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2026-09-02 Started on adding JCSC part number on input and output caps
    [Main_PDB.kicad_sch]
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2026-09-13 fixed 4.3kohm 1w resistor footprint
    [Main_PDB.kicad_sch]
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2026-09-22 Small fixes in 6V buck
2026-09-22 added 3d models to PCB and added 3d Models folder
    [ACS758LCB-100U-PFF-T.STEP, CSD18533Q5A.STEP, LM5148RGYR--3DModel-STEP-56544.STEP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]
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2026-09-22 Fixing library
    [2822HC100-RTR--3DModel-STEP-510211.STEP, 52338943_D2TO.stp, Main_PDB.kicad_pcb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]
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2026-09-22 Small fix
    [Main_PDB.kicad_pcb]
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2026-09-23 Added dump resistor terminals and changed some layout
    [90710A037_18-8 Stainless Steel Thin-Profile Hex Nut.STEP, 91292A125_18-8 Stainless Steel Socket Head Screw.STEP, 91477A123_18-8 Stainless Steel Spring Lock Was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]
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2026-09-23 Fixed regen differential mismatch and pullup voltage
    [Main_PDB.kicad_sch]
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2026-09-23 Switched to 6 layers for improved return path
    [Main_PDB.kicad_pcb]
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2026-09-23 small fixes
    [Main_PDB.kicad_pcb, Main_PDB.kicad_sch]
2026-09-23 Input pour no longer extending to edge
    [Main_PDB.kicad_pcb]
2026-09-23 Fixed a few problems with layout and almost finished routing
    [Main_PDB.kicad_pcb]
2026-09-23 Fixed XT30 polarity
    [Main_PDB.kicad_pcb, Main_PDB.kicad_sch]
2026-09-24 added LCSC numbers and datasheets for resistors on spreadsheet
    [Main_PDB.kicad_pcb]
2026-09-24 added LCSC codes + datasheets for resistors on spreadsheet
    [Main_PDB.kicad_sch]
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2026-10-03 reverted to bcb6ef9ac752d2f1aeb97c22fdac82a234e773ab
    [Main_PDB.kicad_pcb, Main_PDB.kicad_sch]
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2026-10-26 Fixed merge, added components, added a second fet and dampning Rs to regen prot
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
